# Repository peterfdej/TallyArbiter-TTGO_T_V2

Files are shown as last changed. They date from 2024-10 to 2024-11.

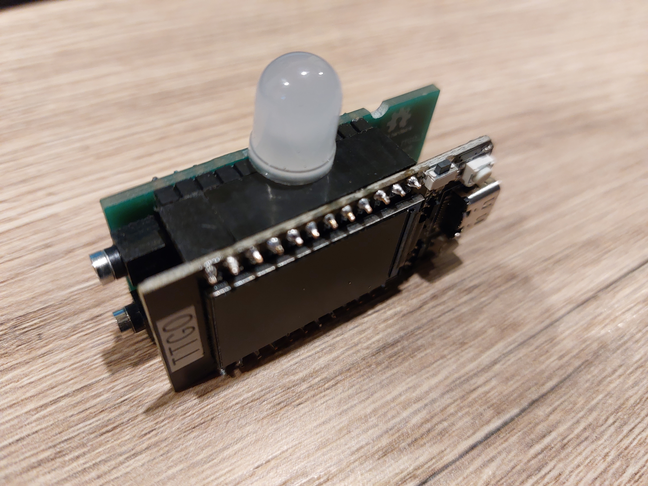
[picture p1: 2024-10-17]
20241009_114131.jpg

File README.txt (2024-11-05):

This version of the TallyArbiter listener is an expanded and improved version of the original TTGO_T listener.
It has a LANC interface to partial control a Sony camera (or other camera's with a LANC interface). With commands in the chat function of TallyArbiter you can zoom the camera and start/stop the recording of the camera. The listener sends back a recording status message in the chat function of TallyArbiter.
It also has a TCP server for connection with the PTZOptics app (https://ptzoptics.com/app-download/). With this app you also can zoom the camera and start/stop recording. I use the preset 7 and 8 for the start and stop recoding command. 
Bitfocus Companion users can use the visca (visca PTZoptics) connection for the same camera control.

The case is a bit larger to hold the extra pcb and battery and I redesigned the front.
The LANC connection has a loop through, so you also can attach a remote control.

You can use the tallysocketserver.py on a TallyArbiter server for communication between Bitfocus Companion and the chatbox of TallyArbiter to send and receive commands to/from a Sony camera.

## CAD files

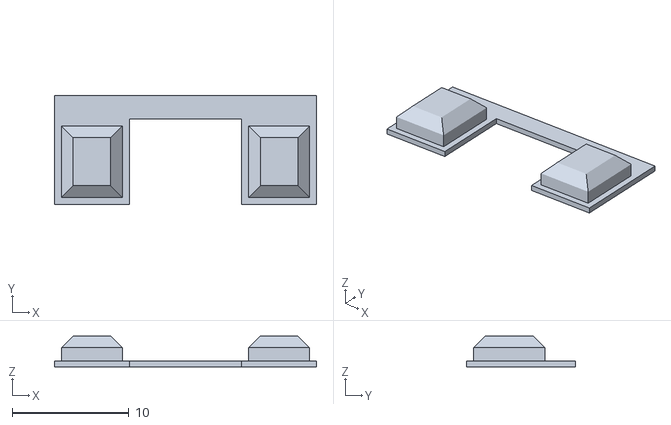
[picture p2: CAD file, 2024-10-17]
TTGO_T-Display_Box_-_Buttons.stl
22.4 x 9.30 x 2.65

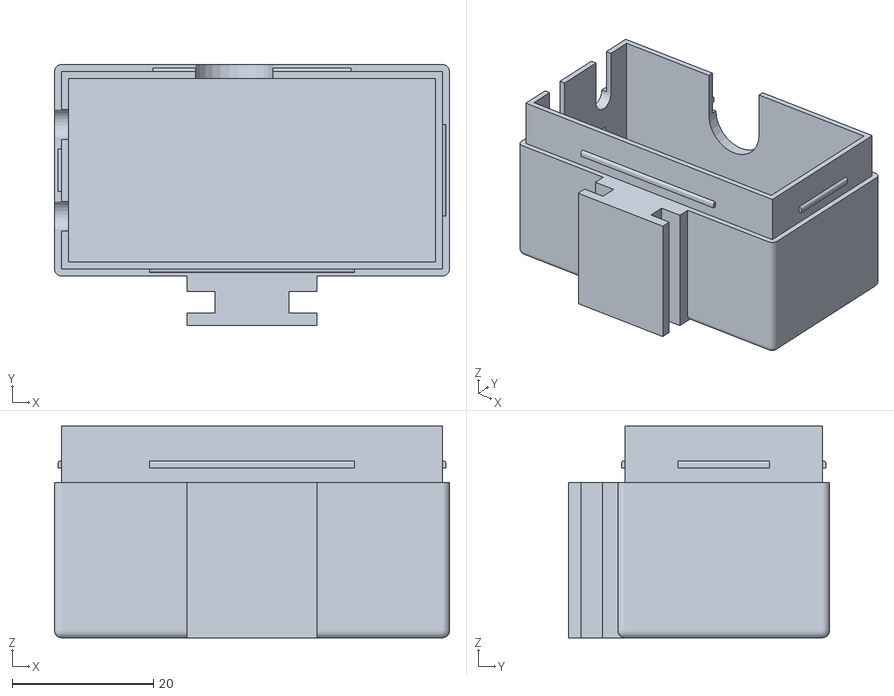
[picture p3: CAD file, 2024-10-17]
TTGO_T-Display_back_V2.stl
56.0 x 37.0 x 30.0

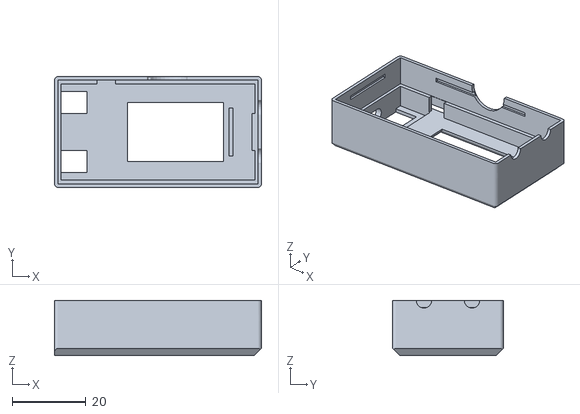
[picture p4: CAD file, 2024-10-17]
TTGO_T-Display_front_V2.stl
56.0 x 30.0 x 15.0

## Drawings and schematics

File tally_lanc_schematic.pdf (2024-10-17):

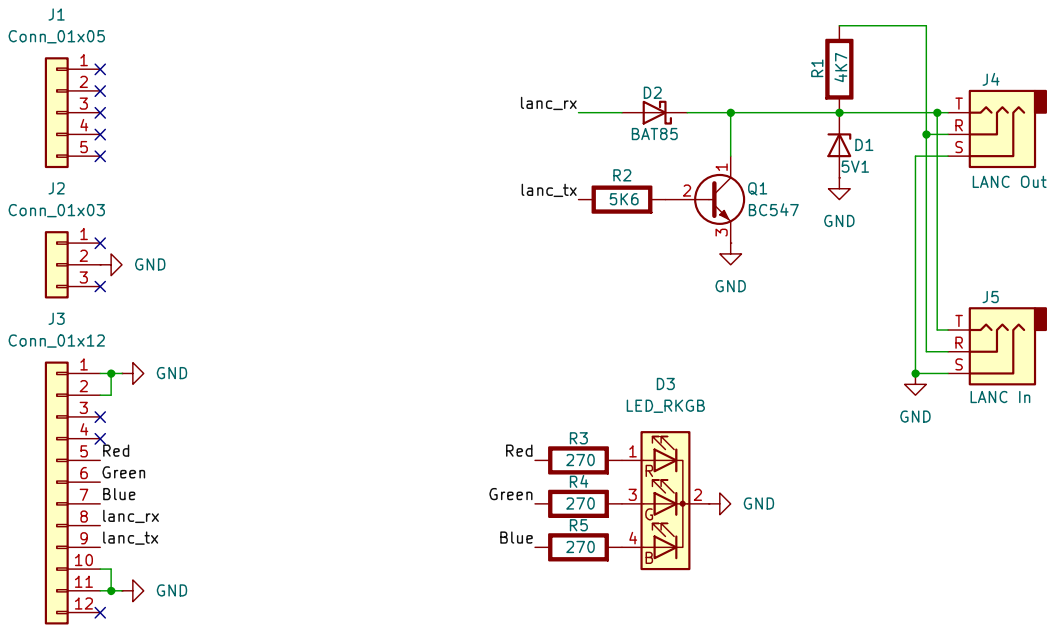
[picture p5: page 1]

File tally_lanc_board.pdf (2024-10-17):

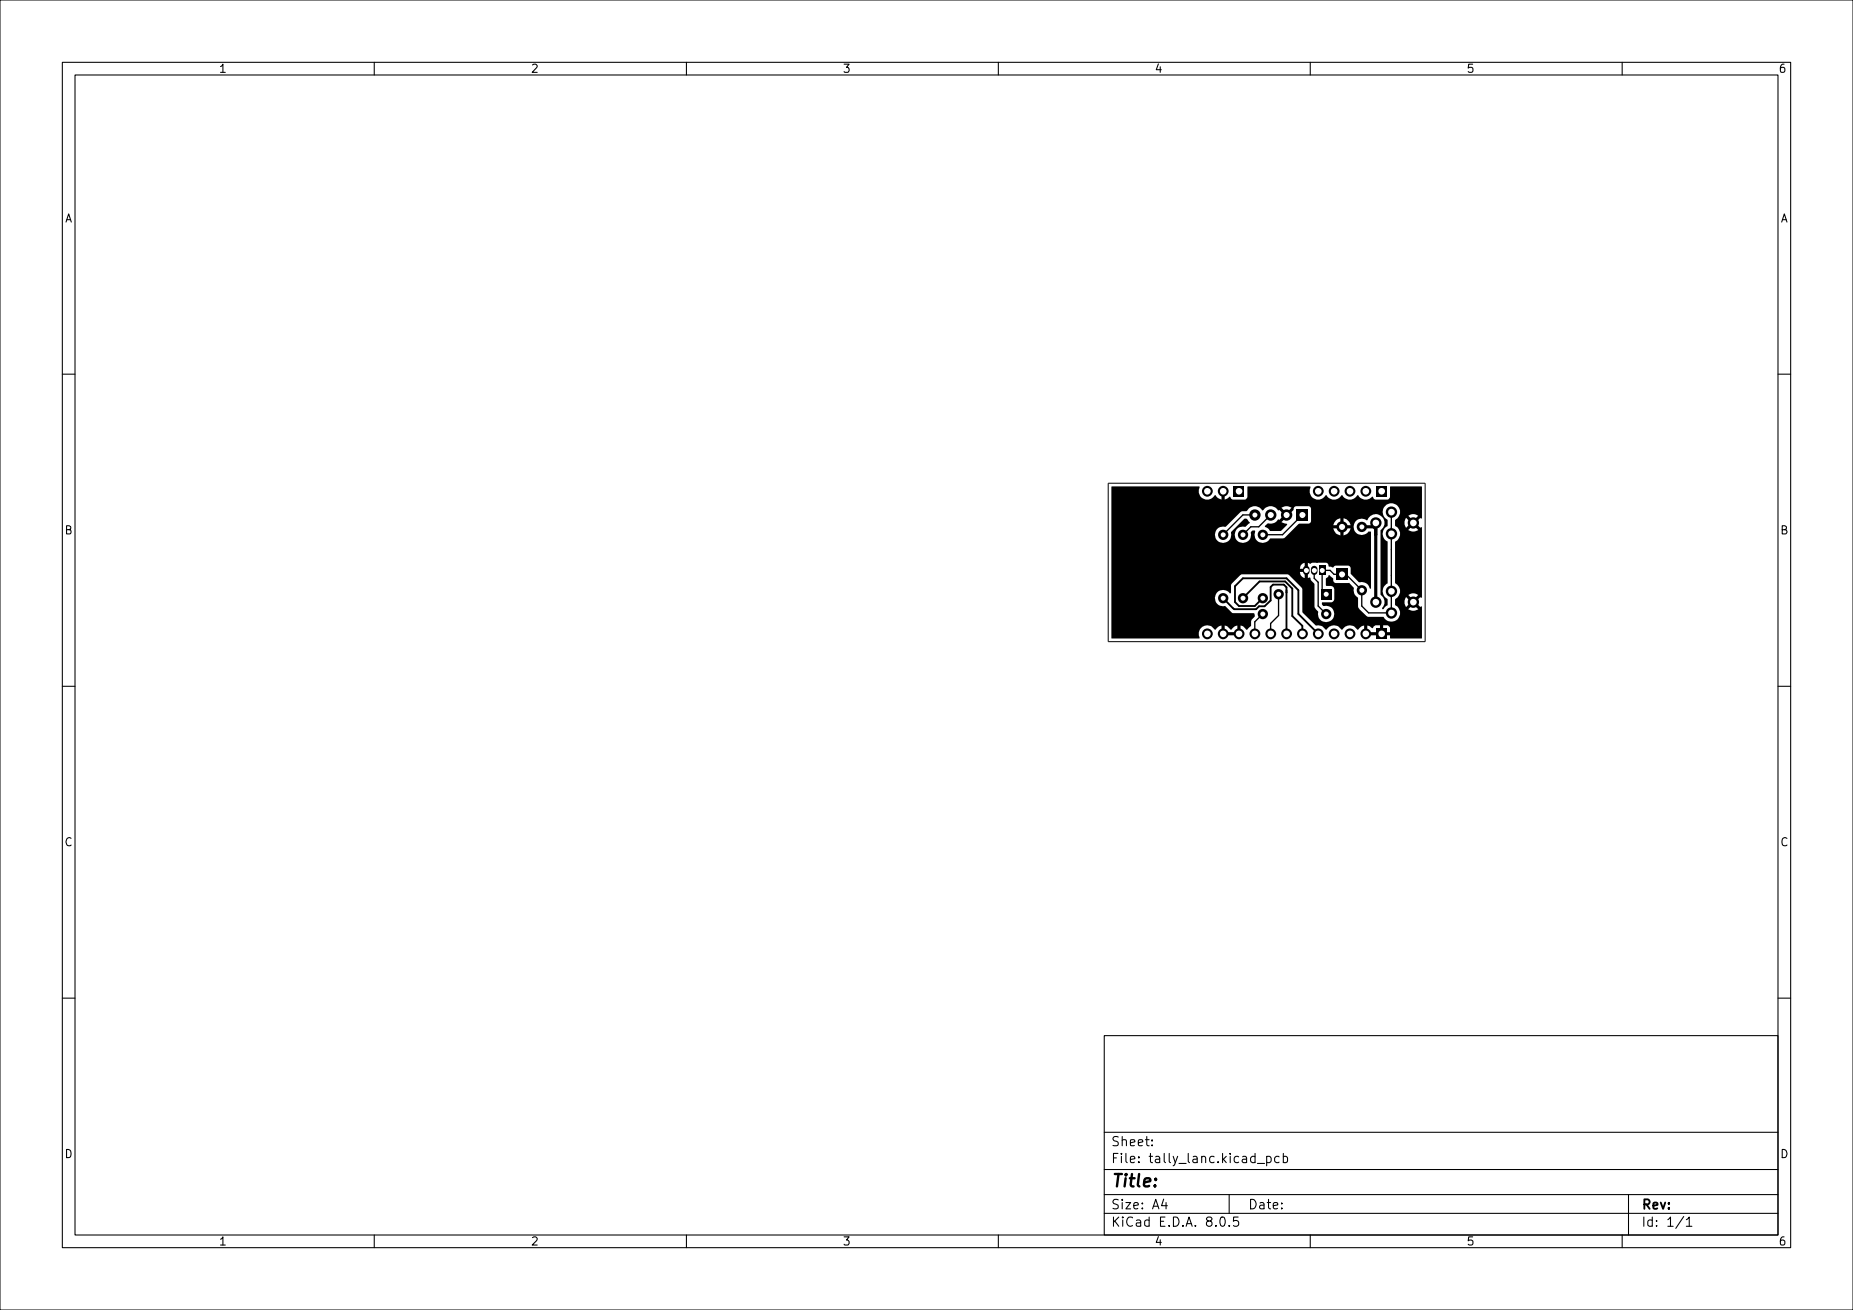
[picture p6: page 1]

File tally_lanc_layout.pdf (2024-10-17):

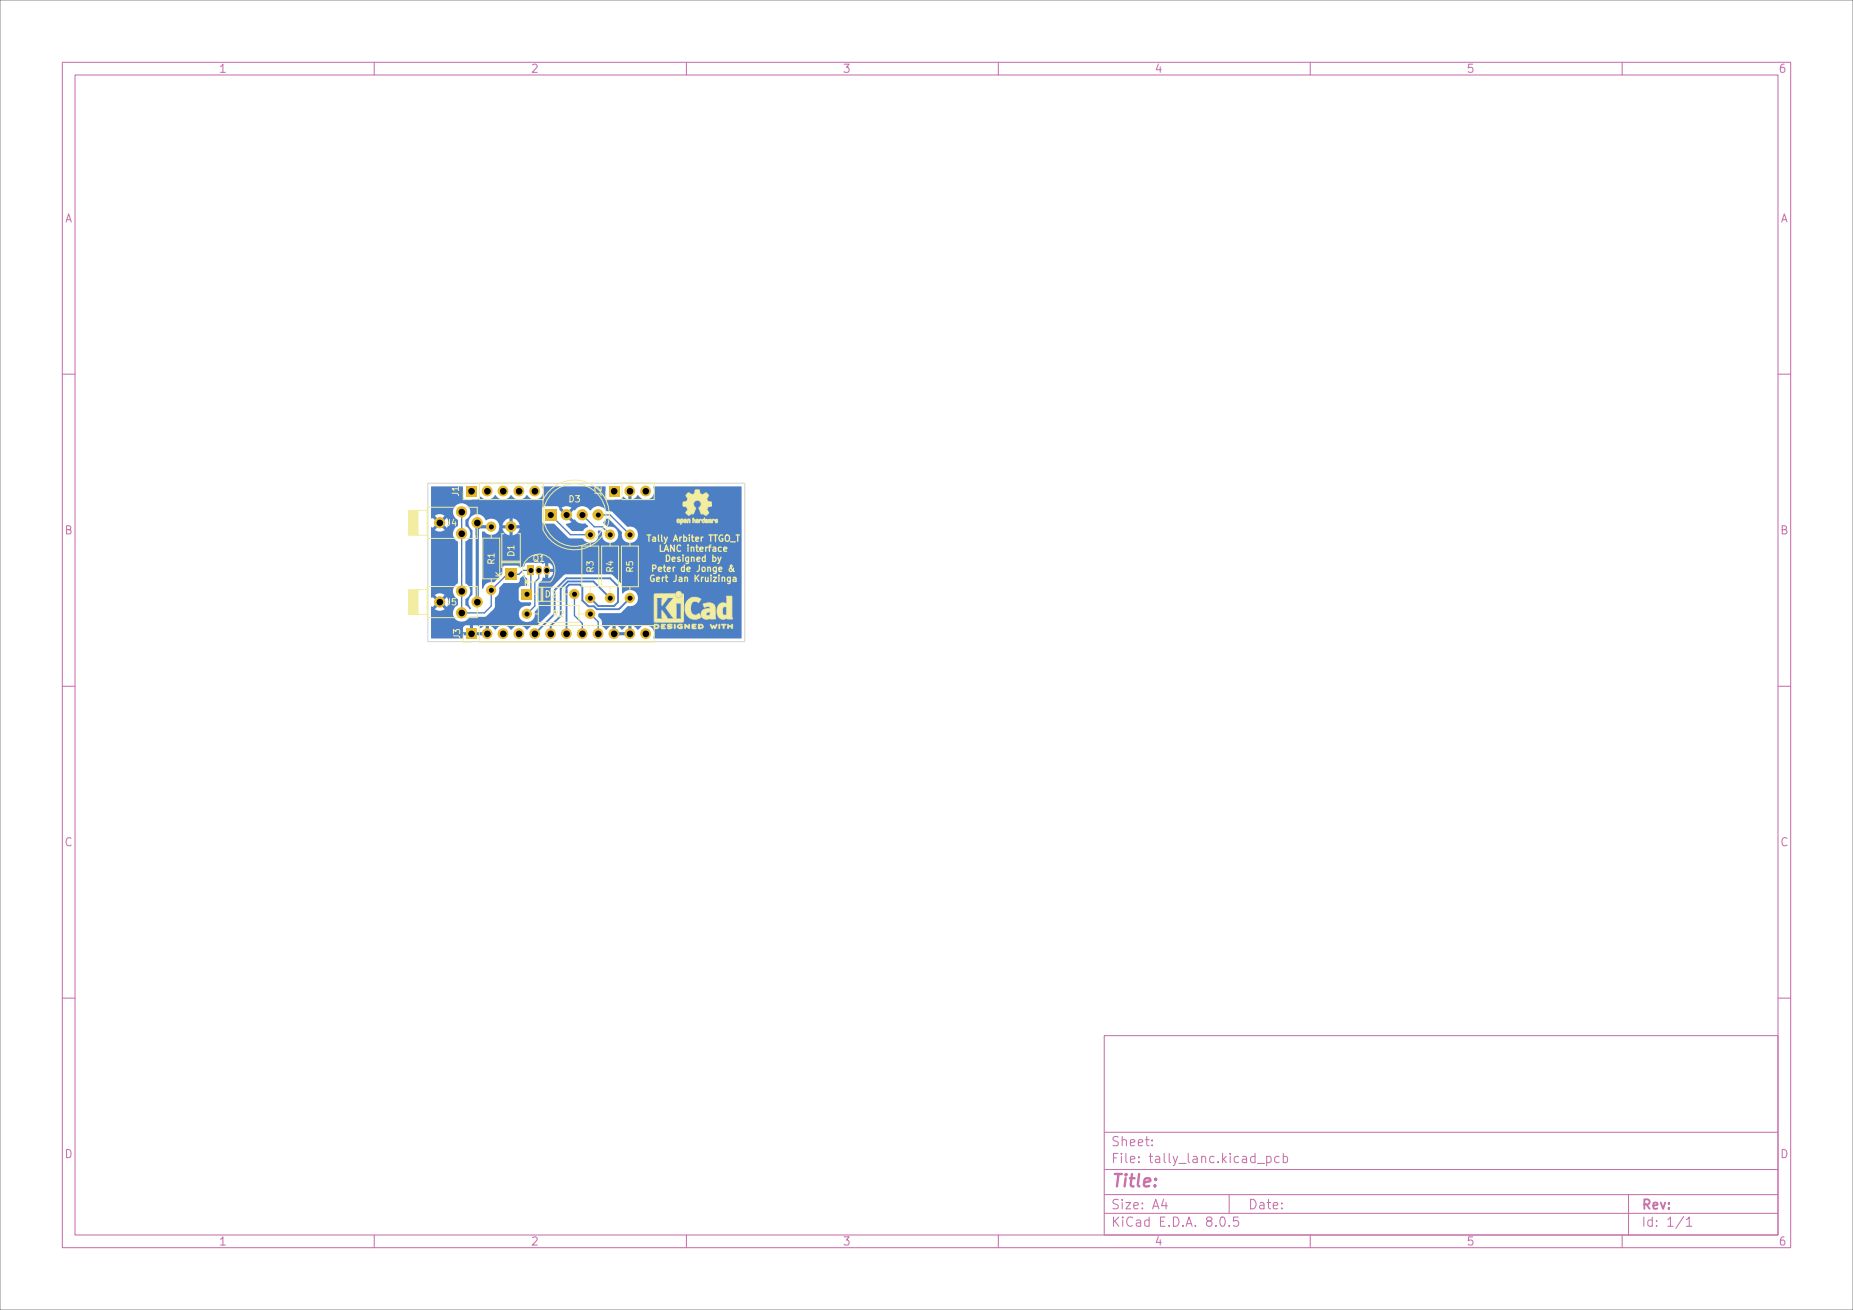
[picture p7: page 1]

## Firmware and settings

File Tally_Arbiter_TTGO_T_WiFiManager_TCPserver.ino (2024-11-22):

/*
#########################################################################################
TTGO-T-display 135x240 1.14"
Board: ESP32 Dev Module
Partition Sceme: Huge AP

Modify User_Setup_Select.h in libraryY TFT_eSPI
  //#include <User_Setup.h>
  #include <User_Setups/Setup25_TTGO_T_Display.h>

include LANC interface.
zoom and record control with PTZOptics APP 
(record on/off = Preset 7 and 8) 
In messaging TallyArbiter #recon or #recoff for all listenerdevices
For specific listenerdevice:
#xxz-t, xxz+t zoom command (xx = firt 2 characters devicername, t = zoomtime 2 ,3 ,4, 5, 6, 7, 8 or 9)
t = 1, start zoom, t = 0, stop zoom
#xxr+ record command  
#########################################################################################
*/
#include <Arduino.h>
#include <AsyncTCP.h>  //TCP server
#include <SocketIOclient.h>
#include <WiFi.h>
#include <TFT_eSPI.h>
#include <Preferences.h>
#include <WiFiManager.h>
#include <PinButton.h>
#include <Arduino_JSON.h>
#include "esp_adc_cal.h"

#define TCP_SERVER_PORT 5678 //PTZOptics-VISCA
#define ADC_EN  14  //ADC_EN is the ADC detection enable port
#define ADC_PIN 34
#define TFT_DISPOFF 0x28
#define TFT_SLPIN   0x10
#define TFT_BL      4        // Display backlight control pin

#define BUTTON_PIN_BITMASK 0x800000001  //gpio 0 + gpio 35 for awake from deep sleep.
                                        //Bottom button long press is deep sleep mode.

#define LANC_INTERFACE true

float battery_voltage;
String voltage;

int vref = 1100;
int batteryLevel = 100;
int barLevel = 0;
int LevelColor = TFT_WHITE;
bool backlight = true;
PinButton btntop(35); //top button, switch screen.
PinButton btnbottom(0); //bottom button, screen on/off
Preferences preferences;

long previousMillis = 0;
long interval = 5000; //interval check LANC connection and recording state

//Tally Arbiter Server
char tallyarbiter_host[40]; //IP address of the Tally Arbiter Server
char tallyarbiter_port[6] = "4455";

TFT_eSPI tft = TFT_eSPI();  // Invoke library, pins defined in User_Setups/Setup25_TTGO_T_Display.h

#if LANC_INTERFACE
const int led_program = 17; //connected with 270ohm resistor
const int led_preview = 2;  //connected with 270ohm resistor
const int led_blue = 15;    //connected with 270ohm resistor
#else
const int led_program = 25; //connected with 270ohm resistor
const int led_preview = 27;  //connected with 270ohm resistor
const int led_blue = 26;    //connected with 270ohm resistor
#endif

WiFiManager wm; // global wm instance
WiFiManagerParameter custom_field; // global param ( for non blocking w params )
bool portalRunning = false;

#if LANC_INTERFACE
//LANC varables
int PinLANC = 13;                // 5V limited input signal from LANC data
int PinCMD = 12;                 // Command to send to LANC
byte typeCam = B00101000;
byte typeVTR = B00011000;
int bitDuration = 104;
byte byte_0;
byte byte_1;
byte byte_2;
byte byte_3;
byte byte_4;
byte byte_5;
byte byte_6;
byte byte_7;
byte statusbyte_1;
byte statusbyte_2;

int zoomt = 0;
int zoomw = 0;
bool recordon = 0;
bool recordoff = 0;
bool recording = 0;
bool lancconnect = 0;
int zoomtime;
TaskHandle_t zoomhandle;
#endif

//Tally Arbiter variables
bool CUT_BUS = true; // true = Programm + Preview = Red Tally; false = Programm + Preview = Yellow Tally screen
bool LAST_MSG = true; // true = show messages on tally screen
SocketIOclient socket;
JSONVar BusOptions;
JSONVar Devices;
JSONVar DeviceStates;
String DeviceId = "unassigned";
String DeviceName = "Unassigned";
String LastMessage = "";
String listenerDeviceName = "TTGO_T-1";
String boxnaam = "";

String prevType = ""; // reduce display flicker by storing previous state
String actualType = "";
String actualColor = "";
int actualPriority = 0;
bool mode_preview = false;  
bool mode_program = false;
bool tallyconnected = 0;

//General Variables
bool networkConnected = false;
int currentScreen = 0;        //0 = Tally Screen, 1 = Settings Screen

void setup(void) {
  Serial.begin(115200);
  while (!Serial);
/*
  ADC_EN is the ADC detection enable port
  If the USB port is used for power supply, it is turned on by default.
  If it is powered by battery, it needs to be set to high level
  */
  pinMode(ADC_EN, OUTPUT);
  digitalWrite(ADC_EN, HIGH);
  //check if top button is pressed at boot for wifimanager setup mode
  if (digitalRead(35) == 0) {
    wm.resetSettings();
  }

  #if LANC_INTERFACE
  pinMode(PinLANC, INPUT_PULLUP); //listens to the LANC line
  pinMode(PinCMD, OUTPUT); //writes to the LANC line
  digitalWrite(PinCMD, LOW); //set LANC line to +5V
  #else
  setCpuFrequencyMhz(80);    //Save battery by turning down the CPU clock
  #endif

  pinMode(led_blue, OUTPUT);
  digitalWrite(led_blue, HIGH);
  Serial.println("Blue LED ON.");
  pinMode(led_program, OUTPUT);
  pinMode(led_preview, OUTPUT);

  logger("Initializing TTGO.", "info-quiet");
 
  btStop();                  //Save battery by turning off BlueTooth
  
  #if LANC_INTERFACE
  xTaskCreatePinnedToCore(  //Task on core 0 to make zoom smooth.
    zoom,
    "Zoom Tele or Wide",
    800,
    NULL,
    1,
    &zoomhandle,
    0
  );
  #endif

  //uint64_t chipid = ESP.getEfuseMac();
  //listenerDeviceName = "TTGO_T-" + String((uint16_t)(chipid>>32)) + String((uint32_t)chipid);
  uint8_t baseMac[6];
  char macchar[6];
  esp_read_mac(baseMac, ESP_MAC_WIFI_STA);
  sprintf(macchar, "%02X%02X%02X", baseMac[3], baseMac[4], baseMac[5]);
  listenerDeviceName = "T-" + String(macchar);


  tft.init();
  tft.setRotation(1);
  cleartftscreen(TFT_BLACK, 2);
  tft.setTextColor(TFT_WHITE);
  tft.setSwapBytes(true);

  logger("Tally Arbiter TTGO Listener Client booting.", "info");
  logger("Listener device name: " + listenerDeviceName, "info");
  preferences.begin("tally-arbiter", false);

  // added to clear out corrupt prefs
  //preferences.clear();
  logger("Reading preferences", "info-quiet");
  if(preferences.getString("deviceid").length() > 0){
    DeviceId = preferences.getString("deviceid");
  }
  if(preferences.getString("devicename").length() > 0){
    DeviceName = preferences.getString("devicename");
  }
  if(preferences.getString("taHost").length() > 0){
    String newHost = preferences.getString("taHost");
    logger("Setting TallyArbiter host as" + newHost, "info-quiet");
    newHost.toCharArray(tallyarbiter_host, 40);
  }
  if(preferences.getString("taPort").length() > 0){
    String newPort = preferences.getString("taPort");
    logger("Setting TallyArbiter port as" + newPort, "info-quiet");
    newPort.toCharArray(tallyarbiter_port, 6);
  }
  preferences.end();

  delay(1000); //wait 100ms before moving on
  cleartftscreen(TFT_BLACK, 2);
  connectToNetwork(); //starts Wifi connection
  //while (!networkConnected) {
  //  delay(200);
  //}

  #if LANC_INTERFACE
  //connectToServer(); // connect TallyArbiter server
  AsyncServer *server = new AsyncServer(TCP_SERVER_PORT); // start listening on tcp port 5678 for PTZ commands
	server->onClient(&handleNewClient, server);
	server->begin();
  #endif
}

void loop() {
  if (!networkConnected && !portalRunning)  {
    cleartftscreen(TFT_BLACK, 2);
    digitalWrite(led_blue, LOW);
    logger("Connection failed","info");
    logger("Longpress topbutton", "info");
    logger("for config WiFi", "info");
    logger("or reset device.","info");
    delay(1000);
    digitalWrite(led_blue, HIGH);
    //connectToNetwork();
  }
  if(portalRunning){
    wm.process();
  }
  socket.loop();
  #if LANC_INTERFACE
  unsigned long currentMillis = millis();
  if (tallyconnected){
    if(currentMillis - previousMillis > (interval)) {
      previousMillis = currentMillis;
      lanccheck();
      recordcheck();
    }
  }
  #endif
  btntop.update();
  btnbottom.update();
  showVoltage();
  #if LANC_INTERFACE
  if (recordon && lancconnect) {
    recordstart();
    recordon = 0;
  }
  if (recordoff && lancconnect) {
    recordstop();
    recordoff = 0;
  }
  #endif
  if (btntop.isSingleClick()) {
    switch (currentScreen) {
      case 0:
        showSettings();
        currentScreen = 1;
        break;
      case 1:
        showDeviceInfo();
        currentScreen = 0;
        break;
    }
  }
  if (btntop.isLongClick()) { //wipe WiFi credentials
    wm.resetSettings();
    connectToNetwork();
    //ESP.restart();
  }
  if (btnbottom.isSingleClick()) {
    if (backlight == true) {
      digitalWrite(TFT_BL, LOW);
      backlight = false;
    } else {
      digitalWrite(TFT_BL, HIGH);
      backlight = true;
    }
  }
  if (btnbottom.isLongClick()){ // MutiButton.h static const int LONGCLICK_DELAY   = 1000; // ms
    intosleepmode(); 
  }
  //Serial.println(uxTaskGetStackHighWaterMark(zoomhandle));
  delay(100);
}

#if LANC_INTERFACE
// xTask
void zoom(void * parameter) {
  for(;;){
    if (lancconnect){ 
      while (zoomt > 0) {
        ZoomTele(zoomt);
        delay(20); //a lanc telegram = 16.6 - 20ms
      }
      while (zoomw > 0){
        ZoomWide(zoomw);
        delay(20);
      }
    }
    delay(100);
  }
}
#endif

void cleartftscreen(int background, int textsize) {
  tft.setCursor(0, 0);
  tft.fillScreen(background);
  tft.setTextSize(textsize);
}

void intosleepmode() {
  tft.println("Going into sleepmode");
  delay(3000);
  tft.writecommand(TFT_DISPOFF);
  tft.writecommand(TFT_SLPIN);
  //After using light sleep, you need to disable timer wake, because here use external IO port to wake up
  esp_sleep_disable_wakeup_source(ESP_SLEEP_WAKEUP_TIMER);
  // esp_sleep_enable_ext1_wakeup(GPIO_SEL_35, ESP_EXT1_WAKEUP_ALL_LOW);
  esp_sleep_enable_ext1_wakeup(BUTTON_PIN_BITMASK, ESP_EXT1_WAKEUP_ALL_LOW); 
  //esp_sleep_enable_ext0_wakeup(GPIO_NUM_0, 0);
  delay(200);
  esp_deep_sleep_start();
}
//**********************************************
// WiFi Manager
//
void connectToNetwork() {
  WiFi.mode(WIFI_STA); 
  logger("Connecting to SSID: " + (String)wm.getWiFiSSID(), "info");
  //reset settings - wipe credentials for testing
  //wm.resetSettings();
  WiFiManagerParameter custom_taServer("taHostIP", "Tally Arbiter Server", tallyarbiter_host, 40);
  WiFiManagerParameter custom_taPort("taHostPort", "Port", tallyarbiter_port, 6);
  wm.addParameter(&custom_taServer);
  wm.addParameter(&custom_taPort);
  wm.setSaveParamsCallback(saveParamCallback);

  // If no saved WiFi we assume that configuration is needed via the captive portal
  if (wm.getWiFiIsSaved()) {
    delay(100);
    wm.setEnableConfigPortal(false);
    portalRunning = false;
  } else {
    cleartftscreen(TFT_BLACK, 2);
    logger("Setup mode", "info");
    logger("Connect to:", "info");
    logger(String(listenerDeviceName), "info");
    logger("http://192.168.4.1", "info");
    //wm.setConfigPortalTimeout(120);
    wm.setEnableConfigPortal(true);
    portalRunning = true;
  }

  std::vector<const char *> menu = {"wifi","param","info","sep","restart","exit"};
  wm.setMenu(menu);
  wm.setClass("invert");
  //wm.setConfigPortalTimeout(120);
  wm.setConnectTimeout(10);
  wm.setConnectRetries(2);

  bool res;
  res = wm.autoConnect(listenerDeviceName.c_str()); // AP name for setup
  if (!res) {
    logger("Failed to connect", "info");
    // ESP.restart();
    delay(2000);
  } else {
    logger("connected)", "info");
    networkConnected = true;
    connectToServer(); // connect to TallyArbiter server
  }
}

String getParam(String name) {
  //read parameter from server, for customhmtl input
  String value;
  if (wm.server->hasArg(name)) {
    value = wm.server->arg(name);
  }
  return value;
}

void saveParamCallback() {
  logger("[CALLBACK] saveParamCallback fired", "info-quiet");
  logger("PARAM tally Arbiter Server = " + getParam("taHostIP"), "info-quiet");
  String str_taHost = getParam("taHostIP");
  String str_taPort = getParam("taHostPort");

  logger("Saving new TallyArbiter host", "info-quiet");
  logger(str_taHost, "info-quiet");
  preferences.begin("tally-arbiter", false);
  preferences.putString("taHost", str_taHost);
  preferences.putString("taPort", str_taPort);
  preferences.end();
}

void showVoltage() {
    static uint64_t timeStamp = 0;
    if (millis() - timeStamp > 5000) {
        timeStamp = millis();
        uint16_t v = analogRead(ADC_PIN);
        battery_voltage = ((float)v / 4095.0) * 2.0 * 3.3 * (vref / 1000.0);
        voltage = "Voltage :" + String(battery_voltage) + "V";
        batteryLevel = floor(100.0 * (((battery_voltage * 1.1) - 3.0) / (4.07 - 3.0))); //100%=3.7V, Vmin = 2.8V
        batteryLevel = batteryLevel > 100 ? 100 : batteryLevel;
        barLevel = 133 - (batteryLevel * 133/100);
        if (battery_voltage >= 3){
          LevelColor = TFT_WHITE;
        }
        else {
          LevelColor = TFT_RED;
        }
        if (currentScreen == 0){
          tft.fillRect(232, 0, 8, 135, LevelColor);
          tft.fillRect(233, 1, 6, barLevel, TFT_BLACK);
        }
        if (battery_voltage < 2.8){ //go into sleep,awake with top button
          tft.setRotation(1);
          cleartftscreen(TFT_BLACK, 2);
          tft.setTextColor(TFT_WHITE);
          tft.println("Battery level low");
          tft.println(v); //for debug
          tft.println(battery_voltage);
          delay(5000);
          intosleepmode();
        }
    }
}

#if LANC_INTERFACE
//****************************************
// LANC part
void lanccheck() {
  while (pulseIn(PinLANC, HIGH) < 5000) {
    if (pulseIn(PinLANC, HIGH) == 0) {  //timeout 1 sec, nothing connected
      lancconnect = 0;
      return;
    }
    else {
      lancconnect = 1;
      return;
    }
  }
}

void recordcheck() {
  if (lancconnect){
    if (statuscode() == 0xFB && recording == 0) { //local recording on
      recording = 1;
      SendMessage("Recording on");
    }
    else if (statuscode() == 0xEB && recording == 1) { //local recording off
      recording = 0;
      SendMessage("Recording off");
    }
  }
}

void printbytes(){ //test function
  //Serial.println("******");
  Serial.print(byte_0, HEX);Serial.print(" ");
  Serial.print(byte_1, HEX);Serial.print(" ");
  Serial.print(byte_2, HEX);Serial.print(" ");
  Serial.print(byte_3, HEX);Serial.print(" ");
  Serial.print(byte_4, HEX);Serial.print(" ");
  Serial.print(byte_5, HEX);Serial.print(" ");
  Serial.print(byte_6, HEX);Serial.print(" ");
  Serial.print(byte_7, HEX);Serial.print(" ");
  Serial.println("");
  if (byte_4 == 0xEB){
    Serial.println("Record OFF");
  }
  else if (byte_4 == 0xFB){
    Serial.println("Record ON");
  }
  else {
    Serial.print("Unknown");
  }
}

byte statuscode(){
  readbytes();
  statusbyte_1 = byte_4;
  readbytes();
  if (statusbyte_1 == byte_4){ //value valid
    return statusbyte_1;
  }
  else {
    statusbyte_2 = byte_4;
    readbytes();
    if (statusbyte_1 == byte_4){
      return statusbyte_1;
    }
    else {
      if (statusbyte_2 == byte_4){
        return statusbyte_2;
      }
      else {
        return 0x00;
      }
    } //the odds are nill to get 3 times different status bytes
  }
}

void recordstart() {
  if (statuscode() == 0xEB){ //status is non recording
    sendCMD(typeVTR, B00110011); // start/stop rec. 0x33
    Serial.print("Start recording");
    tft.fillRect(0, 30, 232, 23, TFT_BLACK); // x y width hight
    tft.setCursor(0, 30);
    tft.println("Recording on");
    SendMessage("Recording on");
    recording = 1;
    delay(1000);
    if (statuscode() == 0xEB) {
      sendCMD(typeVTR, B00110011); //send command a second time
    }
  }
  else if (statuscode() == 0xFB){
    Serial.print("Camera already recording");
    SendMessage("Camera already recording");
  }
  else {
    Serial.print("Error in status");
  }
}

void recordstop() {
  if (statuscode() == 0xFB){ //status is recording
    sendCMD(typeVTR, B00110011); // start/stop rec. 0x33
    Serial.print("Stop recording");
    tft.fillRect(0, 30, 232, 23, TFT_BLACK); // x y width hight
    tft.setCursor(0, 30);
    tft.println("Recording off");
    SendMessage("Recording off");
    recording = 0;
    delay(1000);
    if (statuscode() == 0xFB){
      sendCMD(typeVTR, B00110011); //send command a second time
    }
  }
  else if (statuscode() == 0xEB){
    Serial.print("Camera was not recording");
    SendMessage("Camera was not recording");
  }
  else {
    Serial.print("Error is status");
  }
}

void ZoomWide(int Wide) {
  switch(Wide) {
    case 1: //speed 1
    sendCMD(typeCam, B00010000);
    break;
    case 2: //speed 2
    sendCMD(typeCam, B00010010);
    break;
    case 3: //speed 3
    sendCMD(typeCam, B00010100);
    break;
    case 4: //speed 4
    sendCMD(typeCam, B00010110);
    break;
    case 5: //speed 5
    sendCMD(typeCam, B00011000);
    break;
    case 6: //speed 6
    sendCMD(typeCam, B00011010);
    break;
    case 7: //speed 7
    sendCMD(typeCam, B00011100);
    break;
    case 8: //speed 8
    sendCMD(typeCam, B00011110);
    break;
  }
}

void ZoomTele(int Tele) {
  switch(Tele) {
    case 1: //speed 1
    sendCMD(typeCam, B00000000);
    break;
    case 2: //speed 2
    sendCMD(typeCam, B00000010);
    break;
    case 3: //speed 3
    sendCMD(typeCam, B00000100);
    break;
    case 4: //speed 4
    sendCMD(typeCam, B00000110);
    break;
    case 5: //speed 5
    sendCMD(typeCam, B00001000);
    break;
    case 6: //speed 6
    sendCMD(typeCam, B00001010);
    break;
    case 7: //speed 7
    sendCMD(typeCam, B00001100);
    break;
    case 8: //speed 8
    sendCMD(typeCam, B00001110);
    break;
  }
}

void sendCMD(unsigned char cmd1, unsigned char cmd2) {
  for (int     cmdRepeatCount = 0; cmdRepeatCount < 4; cmdRepeatCount++) {
    while (pulseIn(PinLANC, HIGH) < 5000) {
      //if (pulseIn(PinLANC, HIGH) == 0) {  //timeout 1 sec, nothing connected
      //  return;
      //}
    }
    delayMicroseconds(bitDuration); //startbit for byte 0
    for( int i=0; i<8; i++) {
      digitalWrite(PinCMD, (cmd1 & (1<<i) ) ? HIGH : LOW);  //Write bit 0.
      delayMicroseconds(bitDuration - 8); //write takes 8 microseconbds
    }
    digitalWrite(PinCMD, LOW);
    delayMicroseconds(10);
    while (digitalRead(PinLANC)) {
      //Loop as long as the LANC line is +5V during the stop bit
    }
    delayMicroseconds(bitDuration); //startbit for byte 1
    for( int i=0; i<8; i++) {
      digitalWrite(PinCMD, (cmd2 & (1<<i) ) ? HIGH : LOW);  //Write bit 1
      delayMicroseconds(bitDuration - 8);
    }
    digitalWrite(PinCMD, LOW);
  }
}


void readbytes() {
  for (int     cmdRepeatCount = 0; cmdRepeatCount < 4; cmdRepeatCount++) {
    while (pulseIn(PinLANC, HIGH) < 5000) {
    }
    delayMicroseconds(bitDuration + (bitDuration/2)); //startbit for byte 0 + reading point at half bit
    byte_0 = 0;
    for( int i=0; i<8; i++) {
      if (digitalRead(PinLANC)){bitSet(byte_0,i);} //read bit
      delayMicroseconds(bitDuration);
    }
    digitalWrite(PinCMD, LOW);
    delayMicroseconds(10);
    while (digitalRead(PinLANC)) {
      //Loop as long as the LANC line is +5V during the stop bit
    }
    delayMicroseconds(bitDuration + (bitDuration/2)); //startbit for byte 1
    byte_1 = 0;
    for( int i=0; i<8; i++) {
      if (digitalRead(PinLANC)){bitSet(byte_1,i);}
      delayMicroseconds(bitDuration);
    }
    digitalWrite(PinCMD, LOW);
    //next byte 2
    delayMicroseconds(10);
    while (digitalRead(PinLANC)) {
      //Loop as long as the LANC line is +5V during the stop bit
    }
    delayMicroseconds(bitDuration + (bitDuration/2)); //startbit for byte 2
    byte_2 = 0;
    for( int i=0; i<8; i++) {
      if (digitalRead(PinLANC)){bitSet(byte_2,i);}
      delayMicroseconds(bitDuration);
    }
    digitalWrite(PinCMD, LOW);
    //next byte 3
    delayMicroseconds(10);
    while (digitalRead(PinLANC)) {
      //Loop as long as the LANC line is +5V during the stop bit
    }
    delayMicroseconds(bitDuration + (bitDuration/2)); //startbit for byte 3
    byte_3 = 0;
    for( int i=0; i<8; i++) {
      if (digitalRead(PinLANC)){bitSet(byte_3,i);}
      delayMicroseconds(bitDuration);
    }
    digitalWrite(PinCMD, LOW);
    //next byte 4
    delayMicroseconds(10);
    while (digitalRead(PinLANC)) {
      //Loop as long as the LANC line is +5V during the stop bit
    }
    delayMicroseconds(bitDuration + (bitDuration/2)); //startbit for byte 4
    byte_4 = 0;
    for( int i=0; i<8; i++) {
      if (digitalRead(PinLANC)){bitSet(byte_4,i);}
      delayMicroseconds(bitDuration);
    }
    digitalWrite(PinCMD, LOW);
    //nextbyte 5
    delayMicroseconds(10);
    while (digitalRead(PinLANC)) {
      //Loop as long as the LANC line is +5V during the stop bit
    }
    delayMicroseconds(bitDuration + (bitDuration/2)); //startbit for byte 5
    byte_5 = 0;
    for( int i=0; i<8; i++) {
      if (digitalRead(PinLANC)){bitSet(byte_5,i);}
      delayMicroseconds(bitDuration);
    }
    digitalWrite(PinCMD, LOW);
    //nextbyte 6
    delayMicroseconds(10);
    while (digitalRead(PinLANC)) {
      //Loop as long as the LANC line is +5V during the stop bit
    }
    delayMicroseconds(bitDuration + (bitDuration/2)); //startbit for byte 6
    byte_6 = 0;
    for( int i=0; i<8; i++) {
      if (digitalRead(PinLANC)){bitSet(byte_6,i);}
      delayMicroseconds(bitDuration);
    }
    digitalWrite(PinCMD, LOW);
    //nextbyte 7
    delayMicroseconds(10);
    while (digitalRead(PinLANC)) {
      //Loop as long as the LANC line is +5V during the stop bit
    }
    delayMicroseconds(bitDuration + (bitDuration/2)); //startbit for byte 7
    byte_7 = 0;
    for( int i=0; i<8; i++) {
      if (digitalRead(PinLANC)){bitSet(byte_7,i);}
      delayMicroseconds(bitDuration);
    }
    digitalWrite(PinCMD, LOW);
  }
}
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
